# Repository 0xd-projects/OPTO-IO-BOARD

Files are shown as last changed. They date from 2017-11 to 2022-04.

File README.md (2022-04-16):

# OPTO-IO-BOARD

This board provides 16 independent voltage detection channels.  The channels can be configured to detect Open/Ground signals or Open/5-40V signals.  Each channel has a LED that indicates if the channel is ON or OFF, a currently limiting Resistor and an Opto-Isolator.  Each channel is then inputted into the MCP23017 IC that is setup as an Open/Ground detect.  The MCP23017 has an internal 100K internal pullup to 3.3V that is grounded by the Opto-Isolator when the Input is Active.  The MCP23017 samples it's inputs and reports their state over the I2C bus.  The Adafruit HUZZAH32 - ESP32 Feather board is used to poll the MCP23017 and send the current state of the channels over the network.  The HUZZAH32 Feather can be used over Wifi or with the optional Ethernet FeatherWing.

The board was designed to provide a large input voltage range.  The input circuit is a series of two diodes and any input that provides enough current to activate the diodes will trigger the input.  The input trigger point is approximately 33ua because the Opto-isolator only has to sink the 33ua provided by the MCP23017 100K pullup to 3.3V.  A input 0.5V over the two diodes forward voltage is enough to do this.  The minimum input of 5V is more than enough to trigger this as the LED ( approx 2.2V ) and opto-isolator ( approx 1.2V ) have a combined forward voltage of approximately 3.4V and the Opto-isolator has a gain of approximately 70% at this low current level so ( (5V - 3.4V) / 10K ) * 70% => 112ua which is more than the 33ua sourced by the pullup resistor.  Note: Some LEDs can have a forward voltage as high as 3.3V which would result in a current of 35ua just a little bit more than the 33ua required.

If you would like to change the voltage level trigger you can add a Zener diode in series to the input circuit.  The Zener diode will increase the input level trigger by it's value + approximately 5V.  So, if you want to trigger at say 20V you can put a 15V Zener diode in series on the input.

The input voltage is limited by 10K resistor at 1/2W and the max steady state current rating of the input diodes ( Typically 20ma ).  At 40V input there is only approximately 3.66ma of current at 0.133W going through the input circuit this is far below the LED's 20ma max at around 4W.  The input was rated at 40V ( approximately 27% load ) as a very conservative limit not knowing what conditions the circuit would be used in.  The real 50% max input threshold is approximately 53.4V at around 1/4W and 5ma.  The 100% load is approximately 74V at around 1/2W and 7ma.

Folder structure
- doc                : Contains PDFs of the board design and the BOM.
- hw                 : Contains the Gerber and Kiacad design files for the PCB.
- sw/opto            : Contains example source code for using the board with the optional Ethernet FeatherWing.
- sw/opto_wifi       : Contains example source code for using the board with wifi.
- sw/sample_receiver : Contains example source code to receive and print the channel status on change.

You can find an overview of the Adafruit HUZZAH32 - ESP32 board at the link below.
- https://learn.adafruit.com/adafruit-huzzah32-esp32-feather/overview

You can find an overview of the Adafruit Ethernet FeatherWing at the link below.
- https://learn.adafruit.com/adafruit-wiz5500-wiznet-ethernet-featherwing/overview

You can find the MCP23017 data sheet at the link below.
- https://cdn-shop.adafruit.com/datasheets/mcp23017.pdf

To build the code you need to download the following SW :
- HUZZAH32: https://learn.adafruit.com/adafruit-huzzah32-esp32-feather/using-with-arduino-ide
- Ethernet FeatherWing: https://learn.adafruit.com/adafruit-wiz5500-wiznet-ethernet-featherwing/usage
- MCP23017: https://github.com/adafruit/Adafruit-MCP23017-Arduino-Library

To edit the PCB design you can download Kicad at the link below.
- https://www.kicad.org/

## License
The contents of the doc and hw folders are licensed under the [Creative Commons Attribution 3.0 license](http://creativecommons.org/licenses/by/3.0/us/deed.en_US).
The contents of the sw folder is licensed under the [MIT license](http://opensource.org/licenses/mit-license.php).

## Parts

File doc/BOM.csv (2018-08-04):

ID | Value | Type | P# | Link
R1 - R16 | 10K @ 2 W | Optional Resistor | CCF0210K0JKR36 | https://www.mouser.com/ProductDetail/Vishay-Dale/CCF0210K0JKR36
R1 - R16 | 10K @ 1/2 W | Resistor
R17 - R18 | 3.3K @ 1/4 W | Resistor
R19 | 10K @ 1/4W | Resistor
D1 - D16 | LED | Green LED | WP383GDT | https://www.mouser.com/ProductDetail/604-WP383GDT?r=604-WP383GDT
D1 - D16 | LED | Yellow LED | WP383YDT | https://www.mouser.com/ProductDetail/604-WP383YDT?r=604-WP383YDT
D1 - D16 | LED | Red LED | WP513IDT | https://www.mouser.com/ProductDetail/604-WP513IDT?r=604-WP513IDT
D1 - D16 | LED | Red LED | WP113HDT | https://www.mouser.com/ProductDetail/604-WP113HDT?r=604-WP113HDT
U1 - U4 | Opto-Isolator | Transistor Output Optocouplers Optocplr Phototrans 4-CHNL | LTV-847 | https://www.mouser.com/ProductDetail/Lite-On/LTV-847?qs=sGAEpiMZZMteimceiIVCBx3Y662pemTNEFNr76lpuig%3d
U5 | I/O Expanders | Interface - I/O Expanders 16bit Input/Output Exp I2C interface | MCP23017-E/SP | https://www.mouser.com/ProductDetail/Microchip-Technology/MCP23017-E-SP?qs=sGAEpiMZZMtLck3p7ZBovcWu3APnHHes
U6 | HUZZAH32 ESP32 | Adafruit HUZZAH32 ESP32 Feather Board - with Stacking Headers | Adafruit-3619 | https://www.mouser.com/ProductDetail/Adafruit/3619
U6 | Optional | Ethernet FeatherWing | Adafruit-3201 | https://www.mouser.com/ProductDetail/Adafruit/3201
U7 | 3.3 V Voltate Regulator | LDO Voltage Regulators 800MA LDO LINEAR REG | LM1117T-3.3/NOPB | https://www.mouser.com/ProductDetail/Texas-Instruments/LM1117T-33-NOPB?qs=sGAEpiMZZMvu8NZDyZ4K0WKzueYELT5z
C1 | 100 nF | Capacitor
C2 | 10 uF | Capacitor
Optional | 9.6 V | Optional Input Zener Diode | BZX79-C9V1,113 | https://www.mouser.com/ProductDetail/771-BZX79-C9V1113?r=771-BZX79-C9V1113
Optional | 19.1 V | Optional Input Zener Diode | BZX79-C18,113 | https://www.mouser.com/ProductDetail/771-BZX79-C18113?r=771-BZX79-C18113
J1 - J4 |  | Terminal Block | 282834-8 | https://www.mouser.com/ProductDetail/TE-Connectivity/282834-8
J1 - J4 |  | Terminal Block | 20pcs/lot E-Simpo 2.54mm PCB Screw Terminal Block, 2.54mm 150V6A CE Rohs UL (2.54MM 8P) | https://www.amazon.com/20pcs-Simpo-2-54mm-Terminal-150V6A/dp/B01LF9HS22

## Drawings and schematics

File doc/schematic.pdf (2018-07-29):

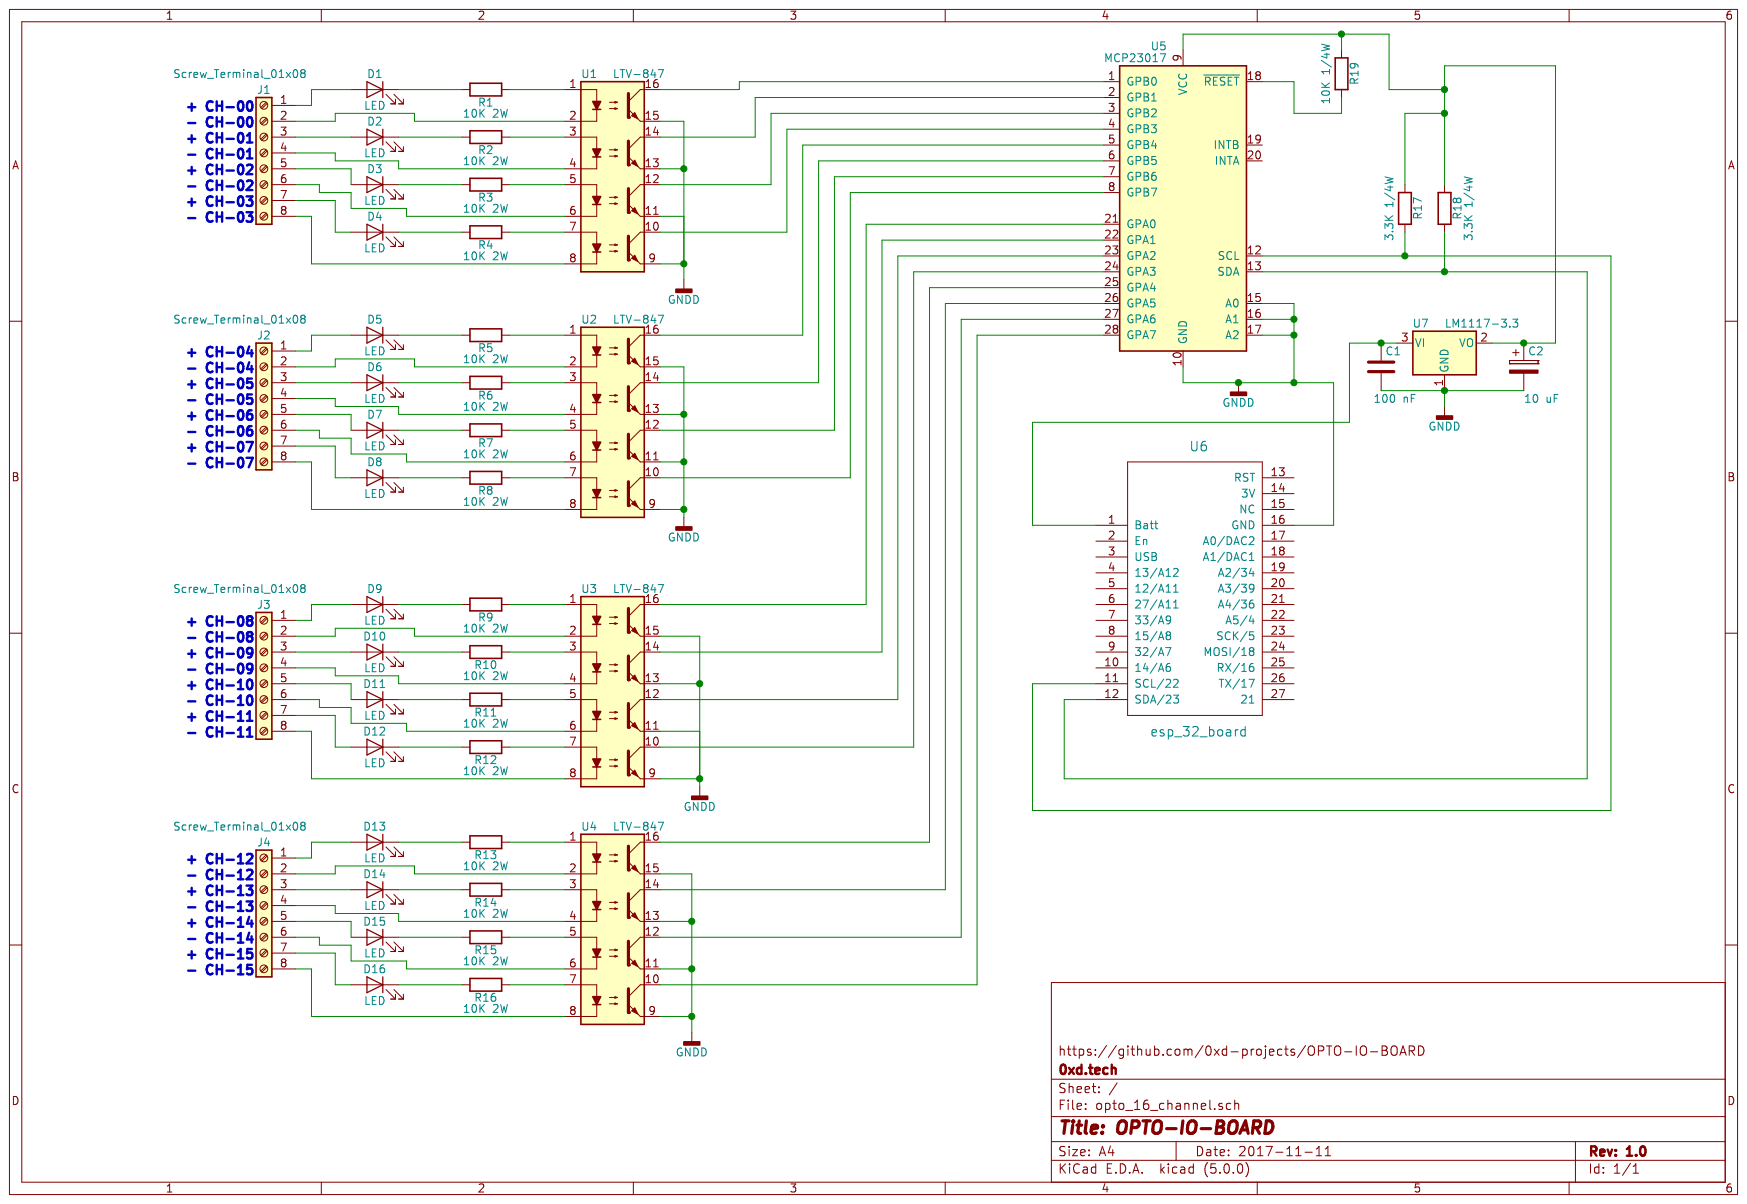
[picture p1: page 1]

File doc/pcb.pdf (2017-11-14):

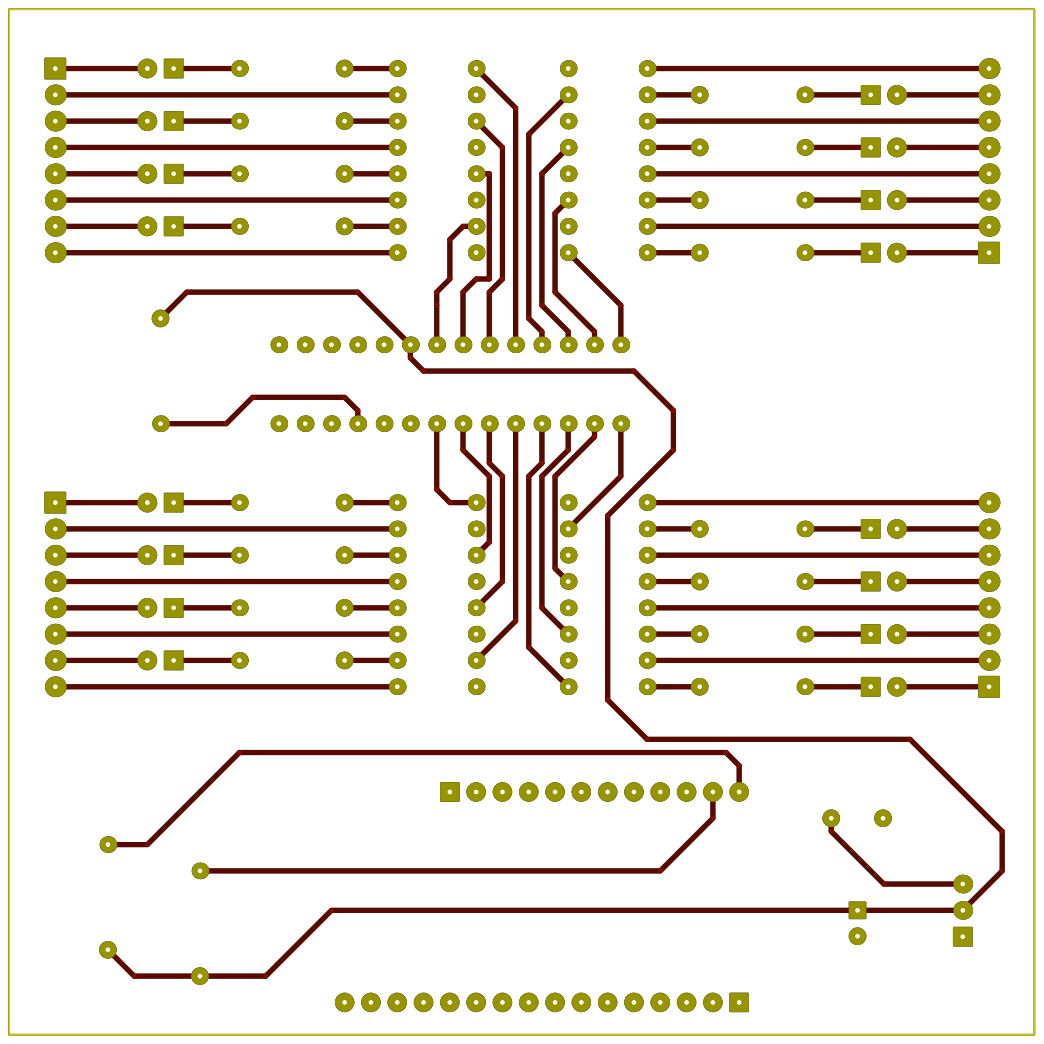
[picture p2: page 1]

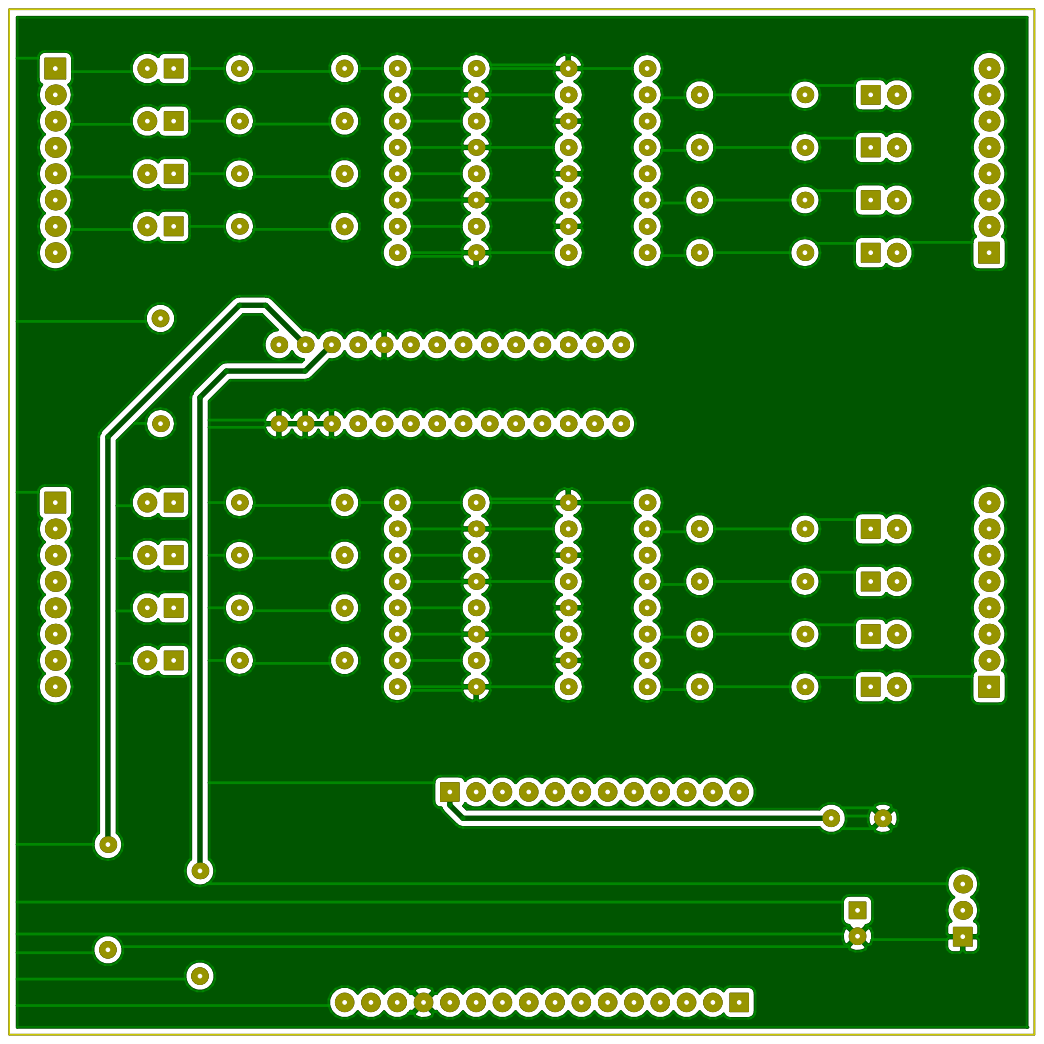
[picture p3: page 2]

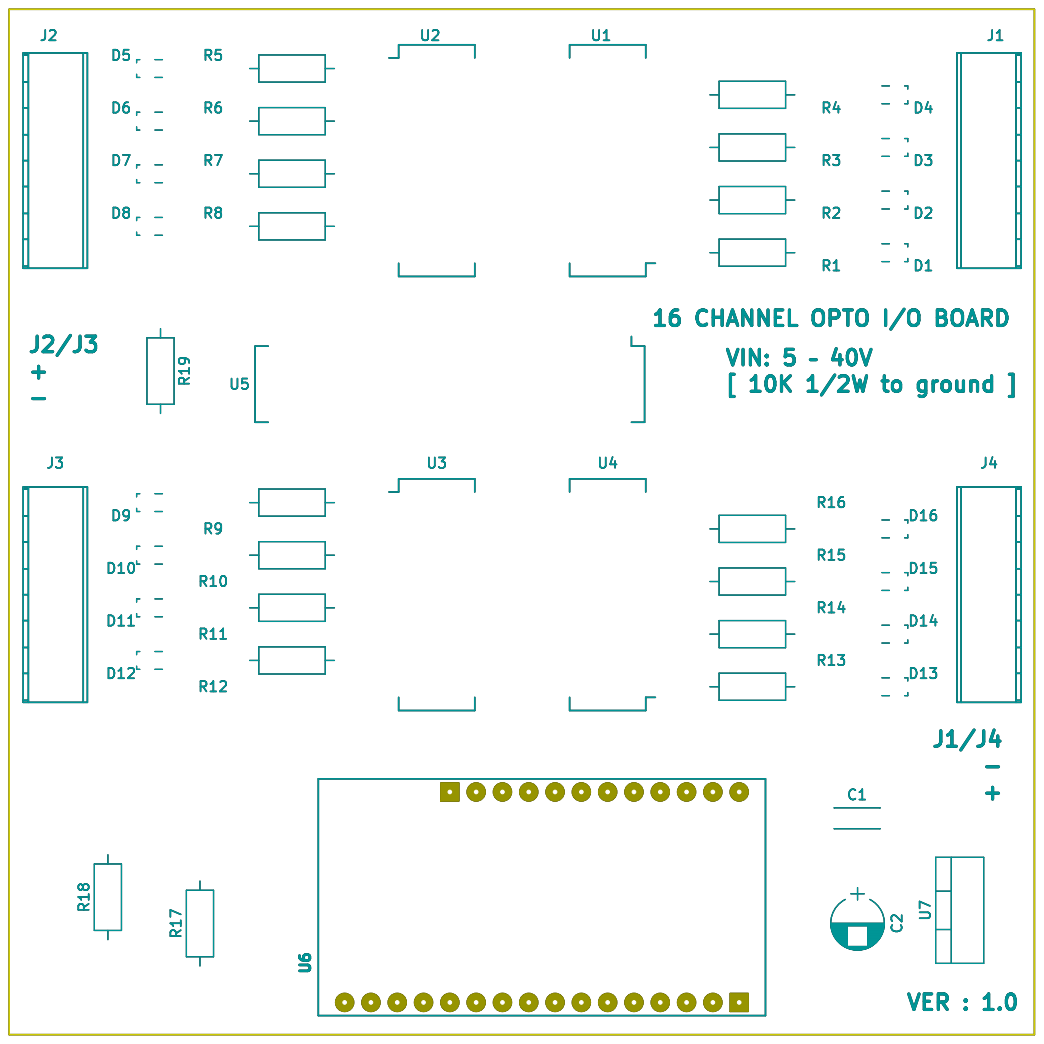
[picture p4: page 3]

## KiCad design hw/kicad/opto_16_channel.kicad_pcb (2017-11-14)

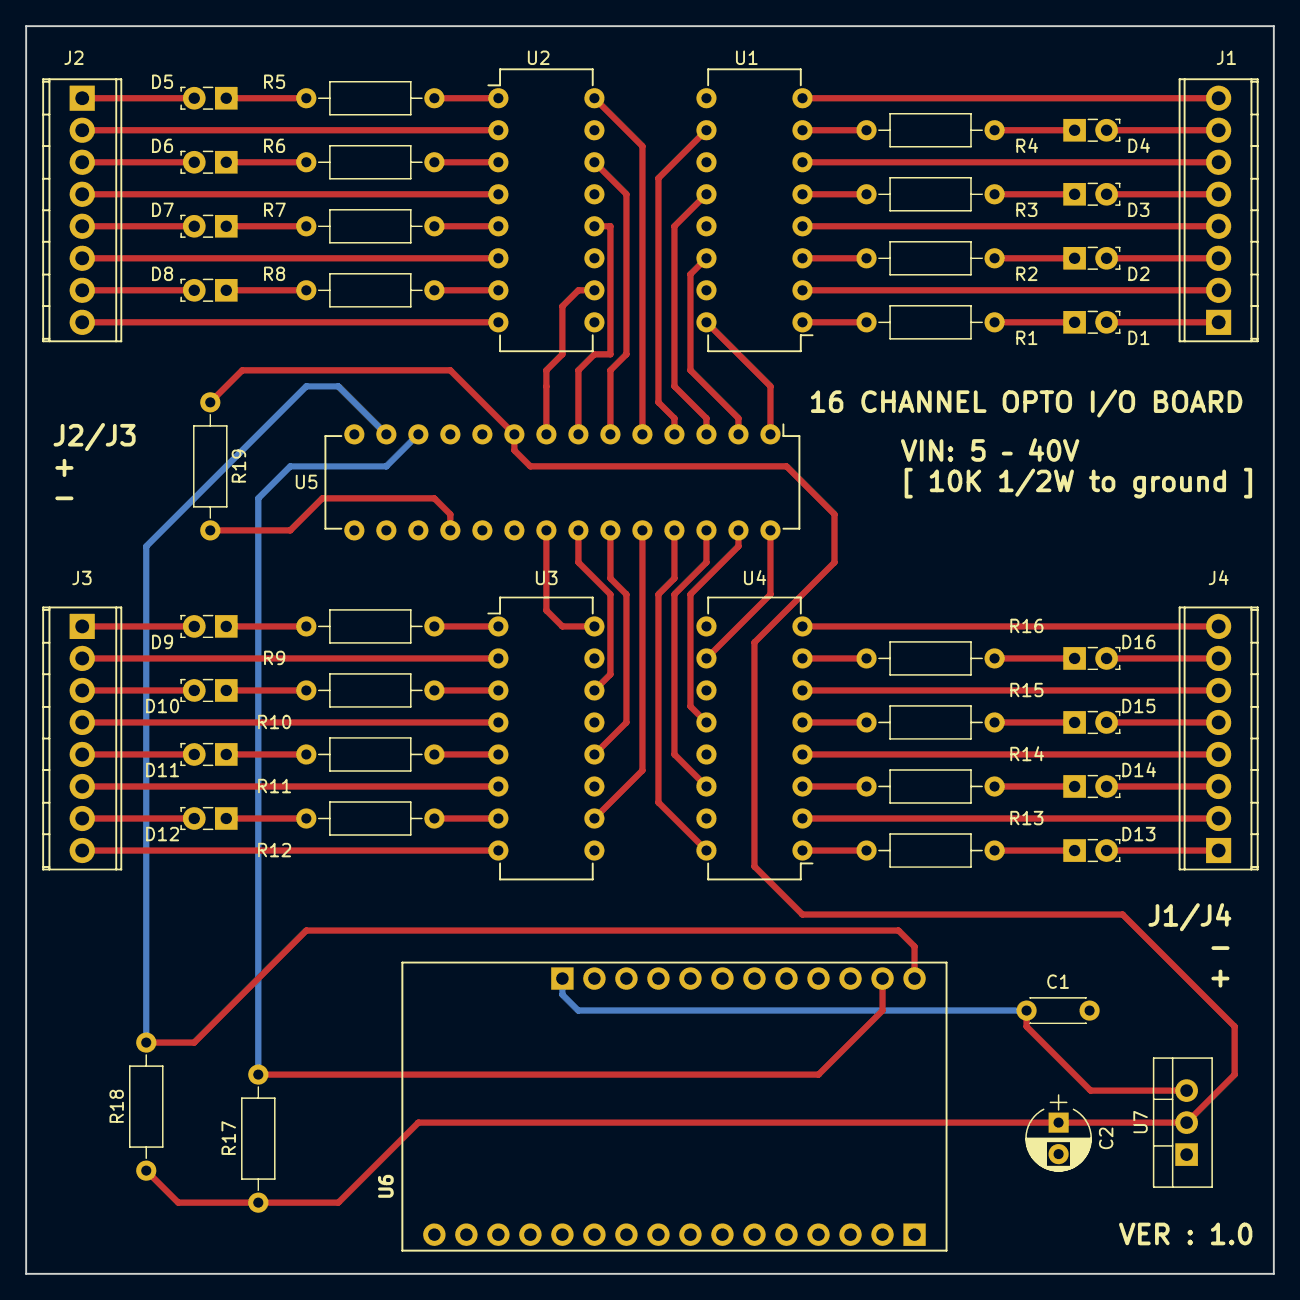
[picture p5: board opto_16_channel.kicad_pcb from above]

Board: 2 copper layers, 99.0 x 99.0 mm, 48 parts (0 on the bottom side), 86 nets.

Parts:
C1: C; C_Disc_D4.3mm_W1.9mm_P5.00mm
C2: CP; CP_Radial_D5.0mm_P2.50mm
D1, D2, D3, D4, D5, D6, D7, D8, D9, D10, D11, D12, D13, D14, D15, D16: LED; LED_SideEmitter_Rectangular_W4.5mm_H1.6mm
J1, J2, J3, J4: Screw_Terminal_01x08; TerminalBlock_Pheonix_MPT-2.54mm_8pol
R1, R2, R3, R4, R5, R6, R7, R8, R9, R10, R11, R12, R13, R14, R15, R16, R17, R18, R19: R; R_Axial_DIN0207_L6.3mm_D2.5mm_P10.16mm_Horizontal
U1, U2, U3, U4: LTV-847; DIP-16_W7.62mm
U5: MCP23017; DIP-28_W7.62mm
U6: esp_32_board; ADAFRUIT_FEATHER
U7: LM1117-3.3; TO-220_Vertical

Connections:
GNDD: C1.2, C2.2, U1.9, U1.11, U1.13, U1.15, U2.9, U2.11, U2.13, U2.15, U3.9, U3.11, U3.13, U3.15, U4.9, U4.11, U4.13, U4.15, U5.10, U5.15, U5.16, U5.17, U6.16, U7.1
unnamed: C1.1, U6.1, U7.3
unnamed: C2.1, R17.1, R18.1, R19.1, U5.9, U7.2
unnamed: D1.1, R1.2
unnamed: D1.2, J1.1
unnamed: D2.1, R2.2
unnamed: D2.2, J1.3
unnamed: D3.1, R3.2
unnamed: D3.2, J1.5
unnamed: D4.1, R4.2
unnamed: D4.2, J1.7
unnamed: D5.1, R5.2
unnamed: D5.2, J2.1
unnamed: D6.1, R6.2
unnamed: D6.2, J2.3
unnamed: D7.1, R7.2
unnamed: D7.2, J2.5
unnamed: D8.1, R8.2
unnamed: D8.2, J2.7
unnamed: D9.1, R9.2
unnamed: D9.2, J3.1
unnamed: D10.1, R10.2
unnamed: D10.2, J3.3
unnamed: D11.1, R11.2
unnamed: D11.2, J3.5
unnamed: D12.1, R12.2
unnamed: D12.2, J3.7
unnamed: D13.1, R13.2
unnamed: D13.2, J4.1
unnamed: D14.1, R14.2
unnamed: D14.2, J4.3
unnamed: D15.1, R15.2
unnamed: D15.2, J4.5
unnamed: D16.1, R16.2
unnamed: D16.2, J4.7
unnamed: J1.2, U1.2
unnamed: J1.4, U1.4
unnamed: J1.6, U1.6
unnamed: J1.8, U1.8
unnamed: J2.2, U2.2
unnamed: J2.4, U2.4
unnamed: J2.6, U2.6
unnamed: J2.8, U2.8
unnamed: J3.2, U3.2
unnamed: J3.4, U3.4
unnamed: J3.6, U3.6
unnamed: J3.8, U3.8
unnamed: J4.2, U4.2
unnamed: J4.4, U4.4
unnamed: J4.6, U4.6
unnamed: J4.8, U4.8
unnamed: R1.1, U1.1
unnamed: R2.1, U1.3
unnamed: R3.1, U1.5
unnamed: R4.1, U1.7
unnamed: R5.1, U2.1
unnamed: R6.1, U2.3
unnamed: R7.1, U2.5
unnamed: R8.1, U2.7
unnamed: R9.1, U3.1
unnamed: R10.1, U3.3
unnamed: R11.1, U3.5
unnamed: R12.1, U3.7
unnamed: R13.1, U4.1
unnamed: R14.1, U4.3
unnamed: R15.1, U4.5
unnamed: R16.1, U4.7
unnamed: R17.2, U5.12, U6.11
unnamed: R18.2, U5.13, U6.12
unnamed: R19.2, U5.18
unnamed: U1.10, U5.4
unnamed: U1.12, U5.3
unnamed: U1.14, U5.2
unnamed: U1.16, U5.1
unnamed: U2.10, U5.8
unnamed: U2.12, U5.7
unnamed: U2.14, U5.6
unnamed: U2.16, U5.5
unnamed: U3.10, U5.24
unnamed: U3.12, U5.23
unnamed: U3.14, U5.22
unnamed: U3.16, U5.21
unnamed: U4.10, U5.28
unnamed: U4.12, U5.27
unnamed: U4.14, U5.26
unnamed: U4.16, U5.25

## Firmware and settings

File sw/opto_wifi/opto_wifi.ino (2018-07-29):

#include "Adafruit_MCP23017.h"

#include <SPI.h>
#include <WiFi.h>
#include <WiFiUdp.h>

#define DEBUG   0           // debug flag to printout all pins and their value
#define DEBUG_T 0           // collects and prints timeing data
#define TX_FREQ 30          // udp tx freq in Hz
#define D_BLINK 500         // number of cycles to hold led high
#define D_PRINT 90000       // number of cycles between printing of timeing debug

#define TX2     0           // enables second transmit, if both ip's are not on the 
                            //  network the transmit will time out and delay the code.

Adafruit_MCP23017 mcp;   // Adafruit libary for the MCP23017 

// WiFi network name and password:
const char* ssid     = "YOUR_SSID";
const char* password = "YOUR_PASSWORD";

IPAddress ip(192, 168, 1, 89);       // local ip, gateway and subnet
IPAddress gateway(192, 168, 1, 1);
IPAddress subnet(255, 255, 255, 0);

unsigned int localPort = 8888;       // local port to listen on

IPAddress ip_r1(192, 168, 1, 88);    // remote ip addresses 1
IPAddress ip_r2(192, 168, 1, 90);    // remote ip addresses 2

// buffers for receiving and sending data
char packetBuffer[ 2 ]; //buffer to hold incoming packet,

// An UDP instance to let us send packets over UDP
WiFiUDP udp;

void setup() 
{  
  mcp.begin();            // use default address 0

  mcp.pinMode( 0, INPUT); // setup discrete pins
  mcp.pinMode( 1, INPUT);
  mcp.pinMode( 2, INPUT);
  mcp.pinMode( 3, INPUT);
  mcp.pinMode( 4, INPUT);
  mcp.pinMode( 5, INPUT);
  mcp.pinMode( 6, INPUT);
  mcp.pinMode( 7, INPUT);
  mcp.pinMode( 8, INPUT);
  mcp.pinMode( 9, INPUT);
  mcp.pinMode(10, INPUT);
  mcp.pinMode(11, INPUT);
  mcp.pinMode(12, INPUT);
  mcp.pinMode(13, INPUT);
  mcp.pinMode(14, INPUT);
  mcp.pinMode(15, INPUT);

  mcp.pullUp(0, HIGH);  // turn on 100K internal pullup for each pin
  mcp.pullUp(1, HIGH); 
  mcp.pullUp(2, HIGH); 
  mcp.pullUp(3, HIGH); 
  mcp.pullUp(4, HIGH); 
  mcp.pullUp(5, HIGH); 
  mcp.pullUp(6, HIGH); 
  mcp.pullUp(7, HIGH); 
  mcp.pullUp(8, HIGH); 
  mcp.pullUp(9, HIGH); 
  mcp.pullUp(10, HIGH); 
  mcp.pullUp(11, HIGH); 
  mcp.pullUp(12, HIGH); 
  mcp.pullUp(13, HIGH); 
  mcp.pullUp(14, HIGH); 
  mcp.pullUp(15, HIGH); 

  pinMode(13, OUTPUT);  // setup pint 13 led output

  Serial.begin(115200); // setup serial port
  delay(1000);
  
  Serial.println("\nDiscrete setup complete");
  Serial.println("\nStarting Network");

  if (!WiFi.config(ip, gateway, subnet)) 
  {
    Serial.println("STA Failed to configure");
  }
  
  Serial.print("Connecting to ");
  Serial.println(ssid);

  WiFi.begin(ssid, password);

  while (WiFi.status() != WL_CONNECTED) 
  {
    delay(500);
    Serial.print(".");
  }

  Serial.println("");
  Serial.println("WiFi connected!");
  Serial.print("IP address: ");
  Serial.println(WiFi.localIP());
  Serial.print("ESP Mac Address: ");
  Serial.println(WiFi.macAddress());
  Serial.print("Subnet Mask: ");
  Serial.println(WiFi.subnetMask());
  Serial.print("Gateway IP: ");
  Serial.println(WiFi.gatewayIP());
  Serial.print("DNS: ");
  Serial.println(WiFi.dnsIP());
  
}



void loop() 
{

  unsigned long m_t1, m_t2, m_t3, m_t4;

  static unsigned long t_last    = 0;
  static unsigned long t_current = 0;
  static unsigned long t_sum     = 0;
  static unsigned long td_last   = 0;
  
  static union                       // union holds discrete data
  {
    unsigned short value;            // allows access to all discrete data at once.
    struct 
    {
      unsigned char d9  : 1; // J3
      unsigned char d10 : 1;
      unsigned char d11 : 1;
      unsigned char d12 : 1;
      
      unsigned char d13 : 1;  // J4
      unsigned char d14 : 1;
      unsigned char d15 : 1;
      unsigned char d16 : 1;
      
      unsigned char d1  : 1; // J1
      unsigned char d2  : 1;
      unsigned char d3  : 1;
      unsigned char d4  : 1;
      
      unsigned char d5  : 1; //J2
      unsigned char d6  : 1;
      unsigned char d7  : 1;
      unsigned char d8  : 1;
    } bits;
  } var;

  static unsigned short last;           // holds the last state of the discretes
  static int            change_count;   // counter used to blink led on discrete change
  static int            print_delay = D_PRINT;
  static int            tx_count    = 0;
  static int            tx_adj      = 0;
  
  const double          freq_ms  = ( 1.0 / TX_FREQ ) * 1000; // period in ms 
  const unsigned int    tx_limit = freq_ms * 1000;           // used to set the the transmit frequencey of the data


  if( change_count > 0 )
  {
    change_count --;          // decrement count each cycle
  }
  else if( change_count == 0 )
  {
    digitalWrite(13, LOW);    // turn the LED off
    change_count = -1;
  }

  unsigned int t_temp =  micros();
  if( ( t_temp - t_last - tx_adj ) >= tx_limit )
  {   

    m_t1 = micros();
    var.value =  ~ mcp.readGPIOAB();
    m_t2=micros();

    if( ( m_t2 - m_t1 ) < 400 )
    {
      Serial.print( "\n ### disc sampple fail \n" );
      digitalWrite(13, HIGH);                          // turn the LED on
      delay(10);
    }
   
    if( var.value != last)
    {
      Serial.print( "Change : " );
      Serial.println( (0x10000 | var.value), BIN);
      digitalWrite(13, HIGH);        // turn the LED on
      change_count = D_BLINK;        // number of cycles to hold high
      
#if DEBUG
      Serial.print( "\n" );
      Serial.print( "\nJ1\n" );
      Serial.print( " d1  : " ); Serial.println(var.bits.d1);
      Serial.print( " d2  : " ); Serial.println(var.bits.d2);
      Serial.print( " d3  : " ); Serial.println(var.bits.d3);
      Serial.print( " d4  : " ); Serial.println(var.bits.d4);
      
      Serial.print( "\nJ2\n" );
      Serial.print( " d5  : " ); Serial.println(var.bits.d5);
      Serial.print( " d6  : " ); Serial.println(var.bits.d6);
      Serial.print( " d7  : " ); Serial.println(var.bits.d7);
      Serial.print( " d8  : " ); Serial.println(var.bits.d8);
  
      Serial.print( "\nJ3\n" );
      Serial.print( " d9  : " ); Serial.println(var.bits.d9);
      Serial.print( " d10 : " ); Serial.println(var.bits.d10);
      Serial.print( " d11 : " ); Serial.println(var.bits.d11);
      Serial.print( " d12 : " ); Serial.println(var.bits.d12);
  
      Serial.print( "\nJ4\n" );
      Serial.print( " d13 : " ); Serial.println(var.bits.d13);
      Serial.print( " d14 : " ); Serial.println(var.bits.d14);
      Serial.print( " d15 : " ); Serial.println(var.bits.d15);
      Serial.print( " d16 : " ); Serial.println(var.bits.d16);
#endif
    }
  
    last = var.value;
    
#if DEBUG_T
    m_t3=micros();
#endif
    
    // send data to remote 1
    udp.beginPacket(ip_r1, 55000);
    udp.write( (const uint8_t*) &var.value, 2);
    udp.endPacket();

#if TX2
    // send data to remote 2
    udp.beginPacket(ip_r2, 55001);
    udp.write( (const uint8_t*) &var.value, 2);
    udp.endPacket();
#endif

    int temp_tx_adj = ( int(tx_limit) - int(td_last) );

    tx_adj = tx_adj + (temp_tx_adj * 0.1);
  
    t_current = micros();
    td_last   = t_current - t_last;
    t_sum    += td_last;
    t_last    = t_current;
    
    tx_count ++;

#if DEBUG_T
    m_t4=micros();
#endif


#if DEBUG_T
      
    if( print_delay <= 0 )
    {
      unsigned long t_delta = t_sum / tx_count;
      
      t_sum    = 0;
      tx_count = 0;
      
      Serial.print("\n TX_FREQ: ");
      Serial.print(TX_FREQ);
  
      Serial.print("  freq_ms: ");
      Serial.print(freq_ms);
  
      Serial.print("  tx_limit: ");
      Serial.print(tx_limit);

      Serial.print(" us  t_delta: ");
      Serial.print( t_delta );
      
      Serial.print(" us  td_last: ");
      Serial.print( td_last );
      Serial.print(" us\n");
      
      Serial.print("\n Delta send : ");
      Serial.print( t_delta );
      Serial.print(" us   Est Freq  : ");
      Serial.print( 1.0 / ( t_delta / 1000.0 / 1000.0 ) );   
  
      Serial.print("\n  Delta I/O : ");
      Serial.print( (m_t2 - m_t1) );
    
      Serial.print(" us     Delta UDP : ");
      Serial.print( (m_t4 - m_t3) );
    
      Serial.print(" us  Total Delta : ");
      Serial.print( (m_t4 - m_t1) / 1000.0 );
      Serial.print(" ms");
    
      Serial.print("\n\n");
  
      print_delay = D_PRINT;
    }

#endif
  }

#if DEBUG_T
  print_delay--;
  
#endif

}

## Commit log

2017-11-13 initial check-in
    [opto_16_channel-B.Cu.gbl, opto_16_channel-B.Mask.gbs, opto_16_channel-B.Paste.gbp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]
2017-11-14 Initial Doc and updates
    [opto_16_channel.kicad_pcb, opto_16_channel.sch]
2018-07-28 Added Wifi, Updated Ethernet
    Added wifi version, updated Ethernet version to 30hz update rate.
2018-08-04 Updated to 10K 1/2W resistor from 10K 2W resistor.
    [BOM.csv]
2022-04-16 Update README.md
    Fixed URL to kicad.
